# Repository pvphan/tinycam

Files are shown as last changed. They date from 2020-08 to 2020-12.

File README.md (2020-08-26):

tinycam
---

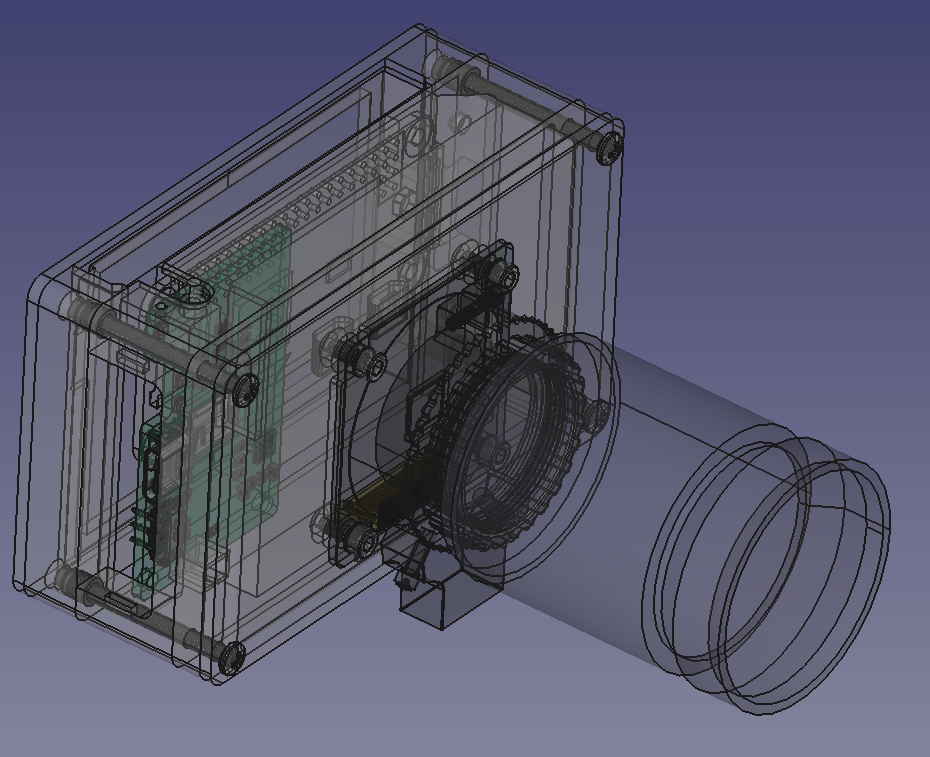
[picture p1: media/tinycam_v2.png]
tinycam_v2 CAD


This is a simple point-and-shoot camera, mostly an excuse to play with the new [Raspberry Pi High Quality camera](https://www.raspberrypi.org/products/raspberry-pi-high-quality-camera/) and ~~maybe~~ **also** a simple PCB for battery management.
The code is a very simple python script wrapping `raspistill`.
CAD is in [FreeCAD](https://www.freecadweb.org/), and any PCBs designed will be [KiCAD](https://kicad-pcb.org/).

Hardware requirements:

- [Raspberry Pi Zero W ($25)](https://www.amazon.com/CanaKit-Raspberry-Wireless-Official-Supply/dp/B071L2ZQZX/)
- [Samsung Evo+ 32 GB microSD card ($9)](https://www.amazon.com/gp/product/B00WR4IJBE)
- [iUniker 2.8" display ($23)](https://www.amazon.com/gp/product/B07H8ZY89H/)
- [Raspberry Pi High Quality camera ($50)](https://www.pishop.us/product/raspberry-pi-hq-camera/?src=raspberrypi)
- [Telephoto lens for HQ camera ($63)](https://www.pishop.us/product/16mm-telephoto-lens-for-raspberry-pi-hq-camera/)
- [Adafruit PowerBoost 1000 Charger ($20)](https://www.adafruit.com/product/2465)
- [tinycam PCB (~$35 to build)](pcb/)

#### next TODO:

- v2 of chassis to support button trigger and battery management
- auto upload to gphotos a la [eshmu/gphotos-upload](https://github.com/eshmu/gphotos-upload)
- support sleep / wake mode
- gallery mode (for local delete)

#### maybe later TODO:

- support video capture mode
- Qt overlay on top of preview for mode switching or adjusting 'manual' controls

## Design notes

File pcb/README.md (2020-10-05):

PCB
---

**WARNING: as of 2020-10-04, this design does not yet work! There is at least one significant deficiency in the PCB layout around the boost converter (TPS61090). I'm still working through the issues, but here are some links to seemingly related problems:**

- [Adafruit board with similar symptoms](https://forums.adafruit.com/viewtopic.php?f=19&t=110556&start=15)
- [TI forum - TPS61090: short circuits at SW pin 3,4 after working for some time](https://e2e.ti.com/support/power-management/f/196/t/642142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)

PCB designed in KiCAD, BOM in DigiKey importable format ([pcb.csv](pcb.csv)).
The PCB is [shared on OSHPark](https://oshpark.com/shared_projects/fBtFeIY9), cost is $11.90 for 3x board with normal prototyping service.

### 3D Model:

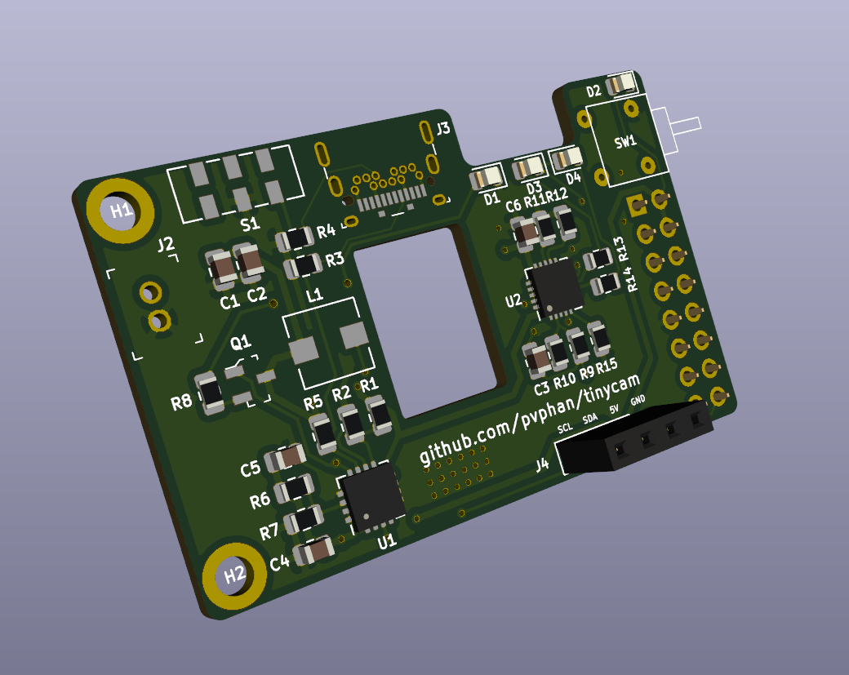
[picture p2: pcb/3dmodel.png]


### Schematic:

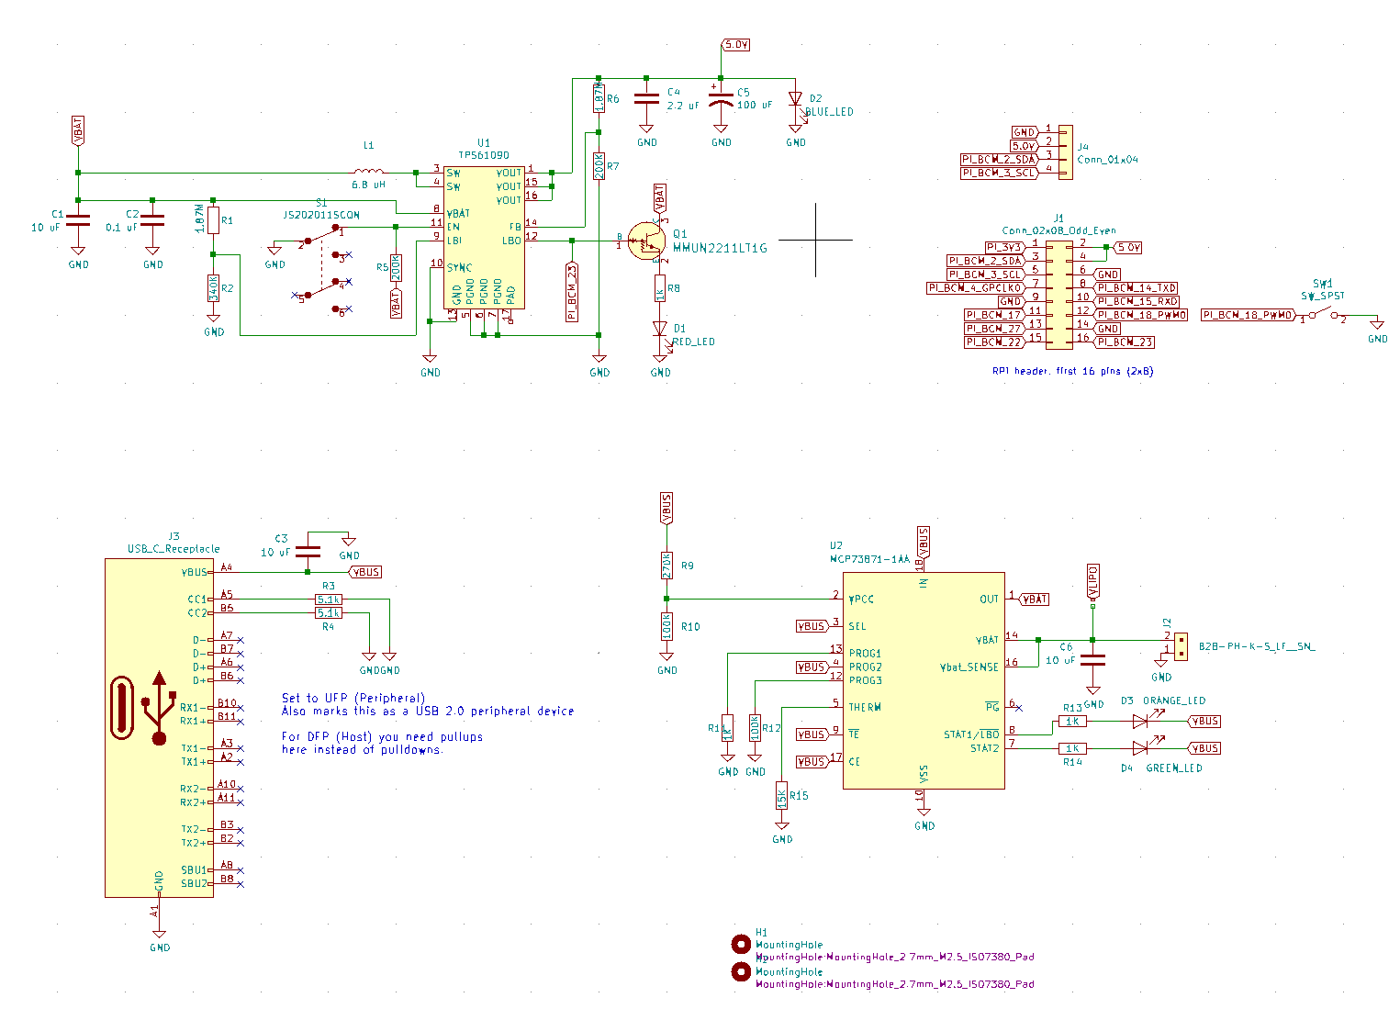
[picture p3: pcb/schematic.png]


### PCB Front:

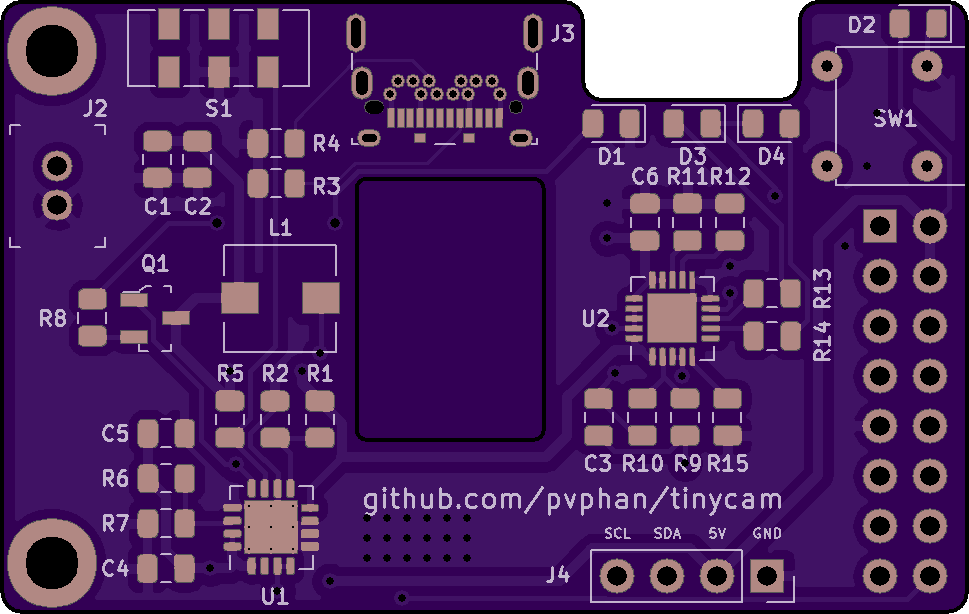
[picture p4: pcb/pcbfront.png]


### PCB Back:

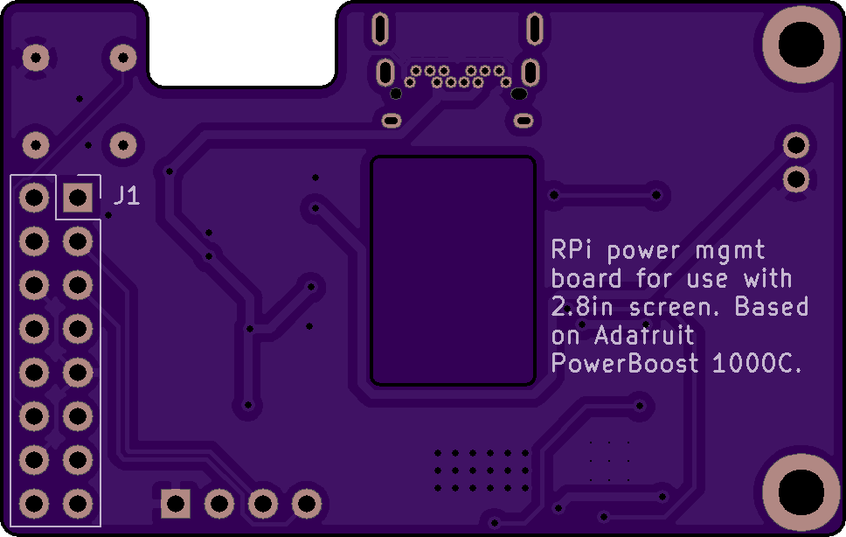
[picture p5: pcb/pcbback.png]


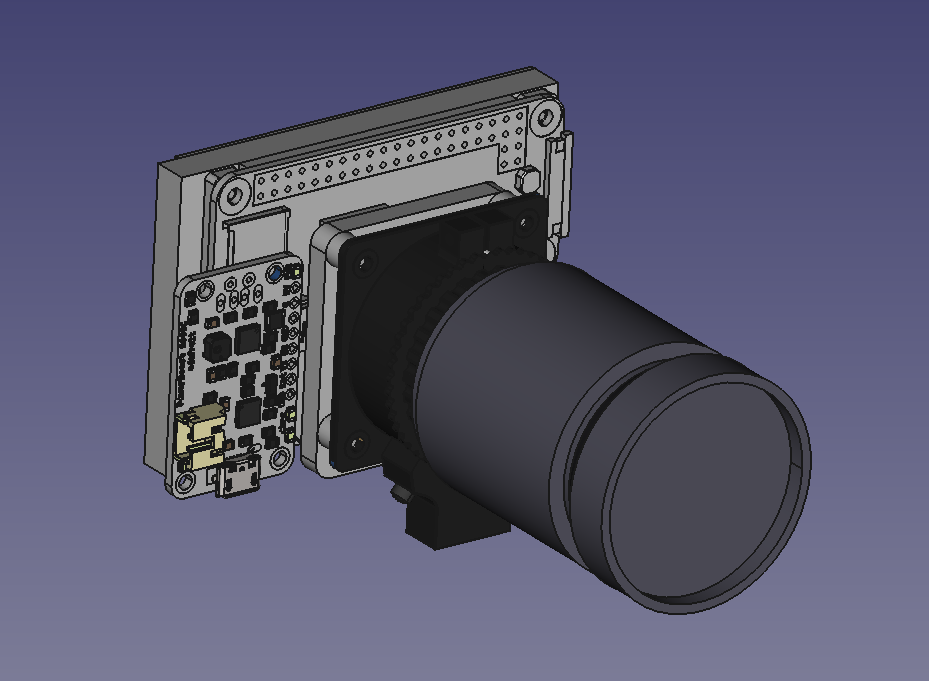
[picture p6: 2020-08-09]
media/tinycam_v1.png

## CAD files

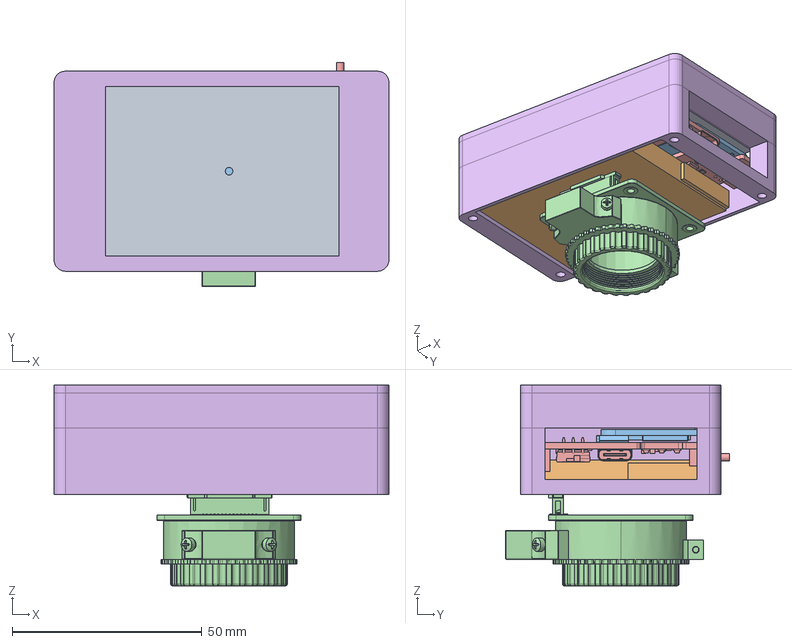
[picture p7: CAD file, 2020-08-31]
cad/main.FCStd
88.2 x 59.0 x 52.8 mm
iunikerscreen28_001
lipo2500mAh_001
rpizerow_001
hqcam_001
pcbpopulated_001
caseback_001

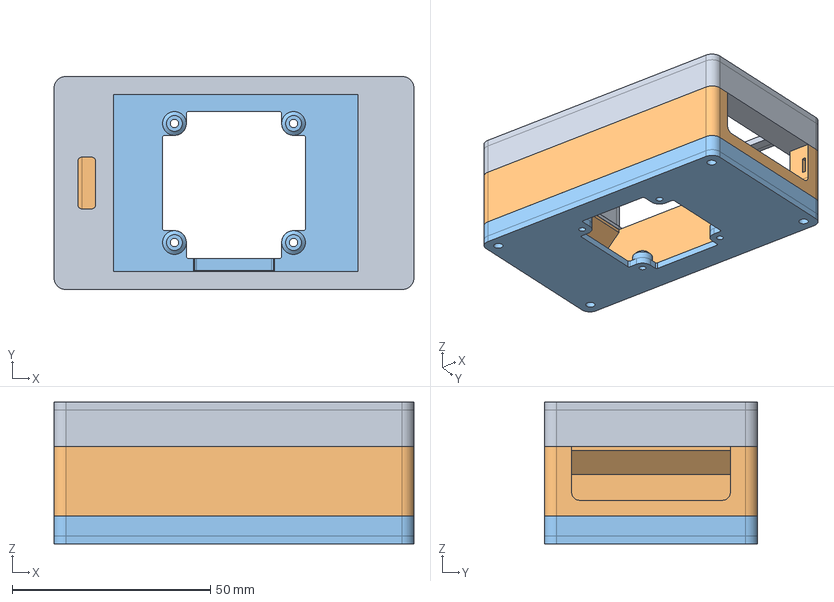
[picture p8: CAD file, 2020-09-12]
cad/caseback.FCStd
90.7 x 53.7 x 35.7 mm
Back
Middle
Front

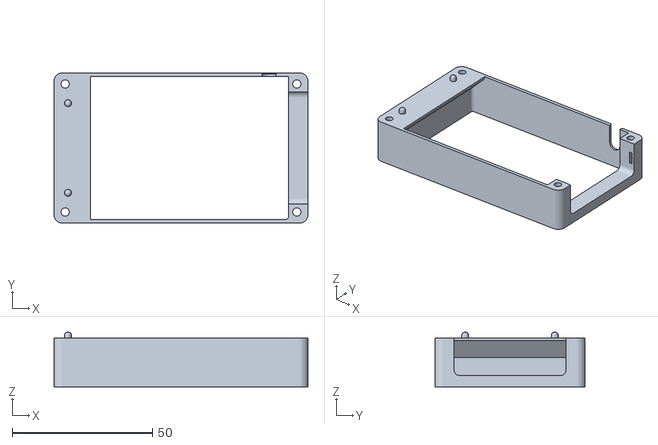
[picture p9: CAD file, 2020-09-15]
output/casemiddle.stl
90.7 x 53.7 x 19.5

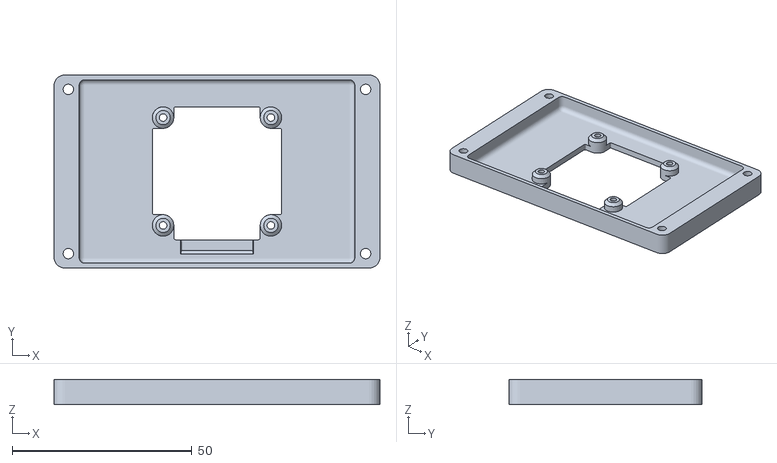
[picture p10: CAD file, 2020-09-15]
output/casefront.stl
90.7 x 53.7 x 7.00

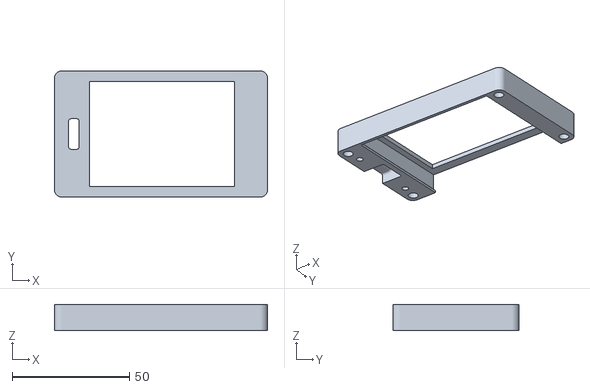
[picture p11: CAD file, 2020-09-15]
output/caseback.stl
90.7 x 53.7 x 11.3

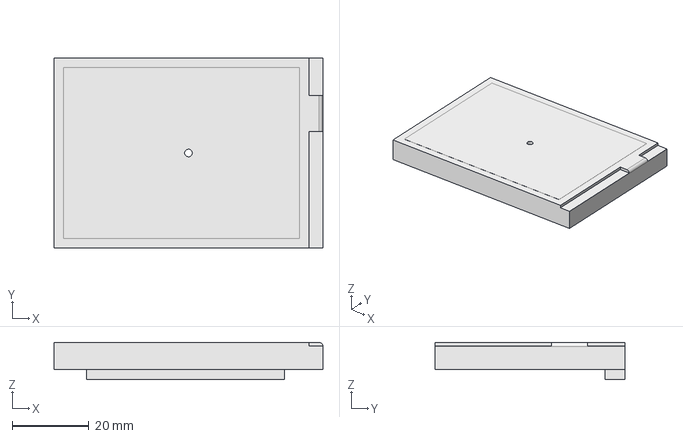
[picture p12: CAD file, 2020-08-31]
cad/iunikerscreen28.FCStd
70.2 x 49.7 x 9.75 mm

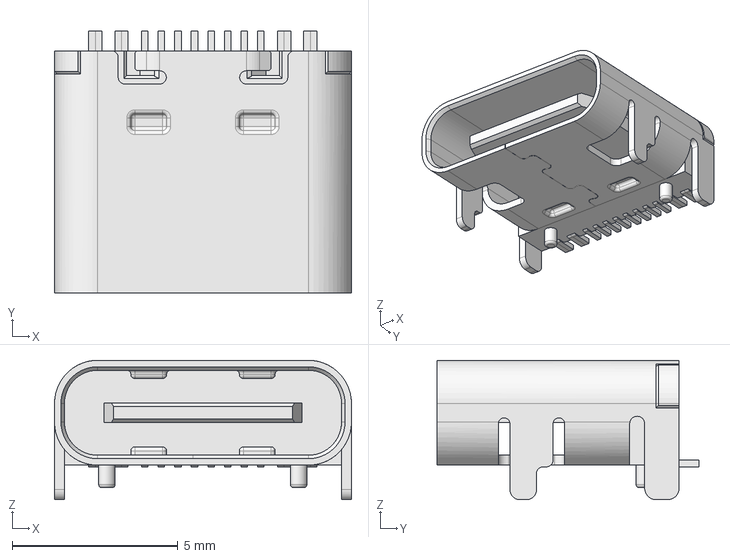
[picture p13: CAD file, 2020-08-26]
cad/usbcfemale.FCStd
8.95 x 7.90 x 4.20 mm

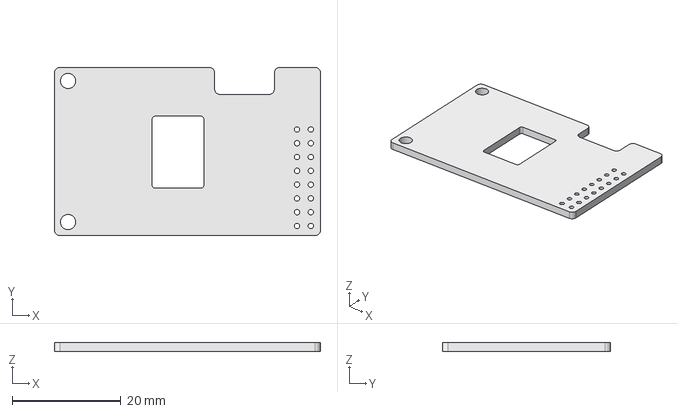
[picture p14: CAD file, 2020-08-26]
cad/pcb.FCStd
49.0 x 31.0 x 1.60 mm

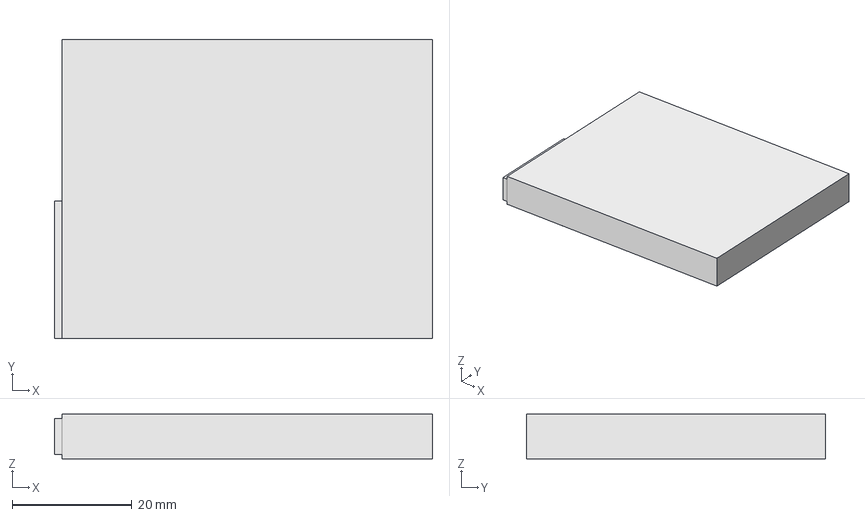
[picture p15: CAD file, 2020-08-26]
cad/lipo2500mAh.FCStd
63.2 x 50.0 x 7.50 mm

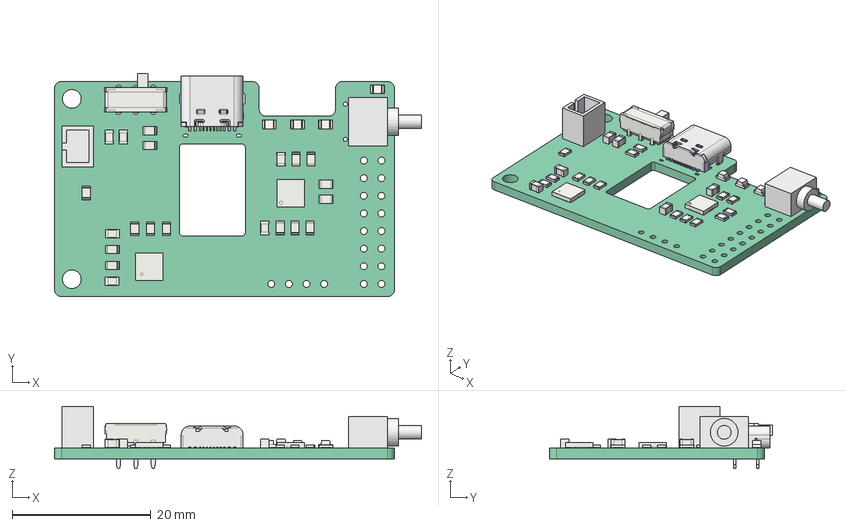
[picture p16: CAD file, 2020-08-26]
cad/pcbpopulated.FCStd
52.9 x 32.2 x 9.00 mm
Pcb_ca95
R15_R_0805_2012Metric_5F4384B2
R14_R_0805_2012Metric_5F41A5F7
R13_R_0805_2012Metric_5F41A621
R12_R_0805_2012Metric_5F41A5CD
R11_R_0805_2012Metric_5F41A5A3
R10_R_0805_2012Metric_5F438482
R9_R_0805_2012Metric_5F438452
R8_R_0805_2012Metric_5F418730
R7_R_0805_2012Metric_5F4188D7
R6_R_0805_2012Metric_5F418706
R5_R_0805_2012Metric_5F418601
R4_R_0805_2012Metric_5F41862B
R3_R_0805_2012Metric_5F4186A6
R2_R_0805_2012Metric_5F4185D7
R1_R_0805_2012Metric_5F4183FD
C5_C_0805_2012Metric_5F418A8F
C4_C_0805_2012Metric_5F418A5F
C2_C_0805_2012Metric_5F41895D
C1_C_0805_2012Metric_5F41892D
C3_C_0805_2012Metric_5F41A650
C6_C_0805_2012Metric_5F43930C
D1_LED_0805_2012Metric_5F4185A5
D2_LED_0805_2012Metric_5F4186D4
D3_LED_0805_2012Metric_5F41A51D
D4_LED_0805_2012Metric_5F41A4E7
S1_SW_CuK_JS202011AQN_DPDT_Angled_5F418324
U1_Texas_S_PVQFN_N16_EP27x27mm_5F41877F
U2_QFN-20-1EP_4x4mm_Pitch0.5mm_5F41A47B
usb-c
switch

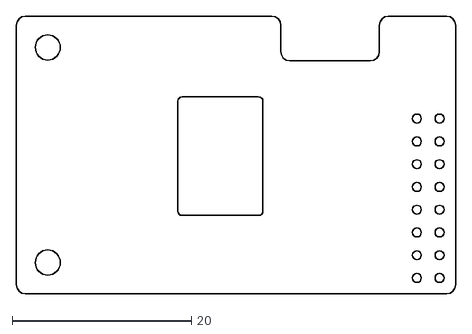
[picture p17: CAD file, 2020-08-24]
cad/pcbfrontface.dxf
49.0 x 31.0

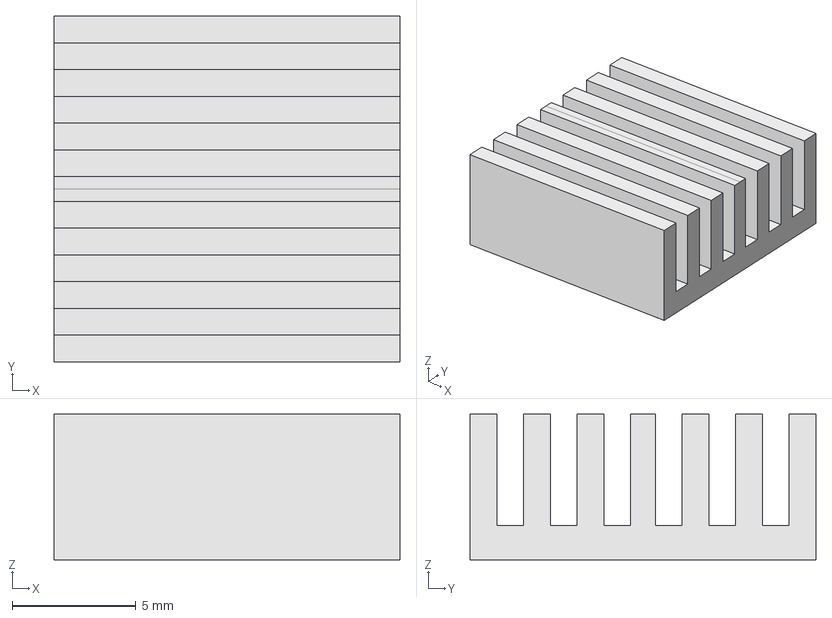
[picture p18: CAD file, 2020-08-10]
cad/heatsink.FCStd
14.0 x 14.0 x 5.90 mm

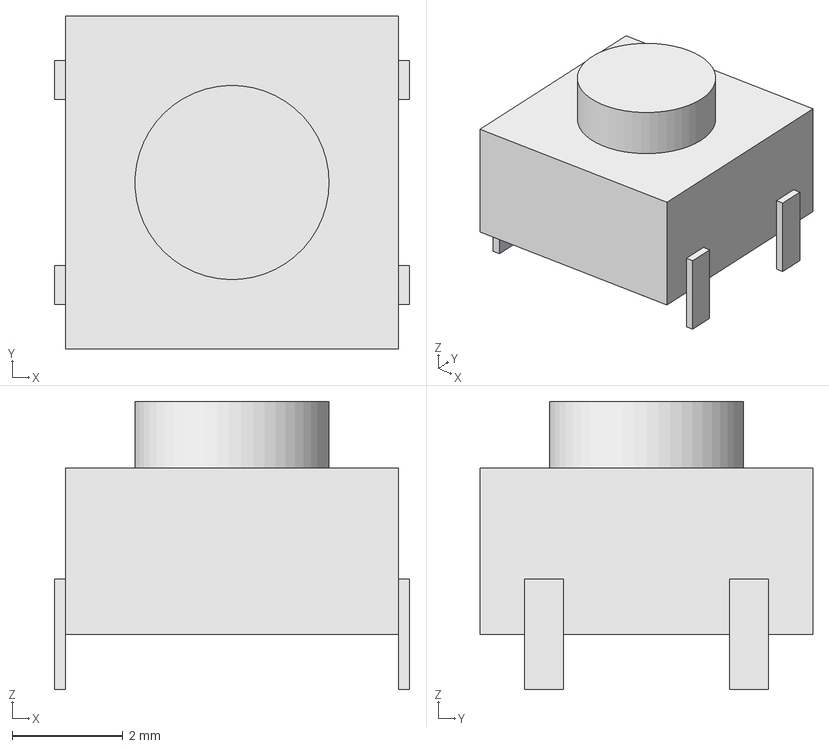
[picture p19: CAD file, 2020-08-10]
cad/button.FCStd
6.40 x 6.00 x 5.20 mm

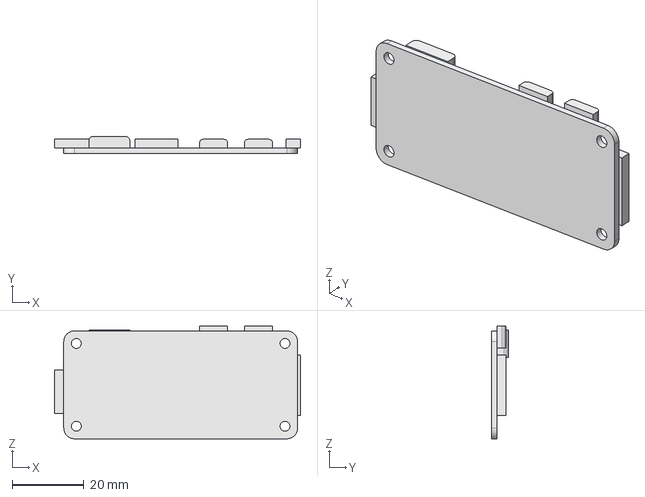
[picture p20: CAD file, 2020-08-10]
cad/pizerow2.FCStd
68.4 x 4.80 x 31.3 mm

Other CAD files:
cad/hqcam.FCStd
cad/PowerBoost1000C.FCStd
cad/telephotolens.FCStd
cad/picamadapter.fcstd
cad/92005A079.FCStd
cad/92290A056.FCStd
cad/94180A323.FCStd
cad/lensmountbracket.FCStd
cad/rpizerow.FCStd

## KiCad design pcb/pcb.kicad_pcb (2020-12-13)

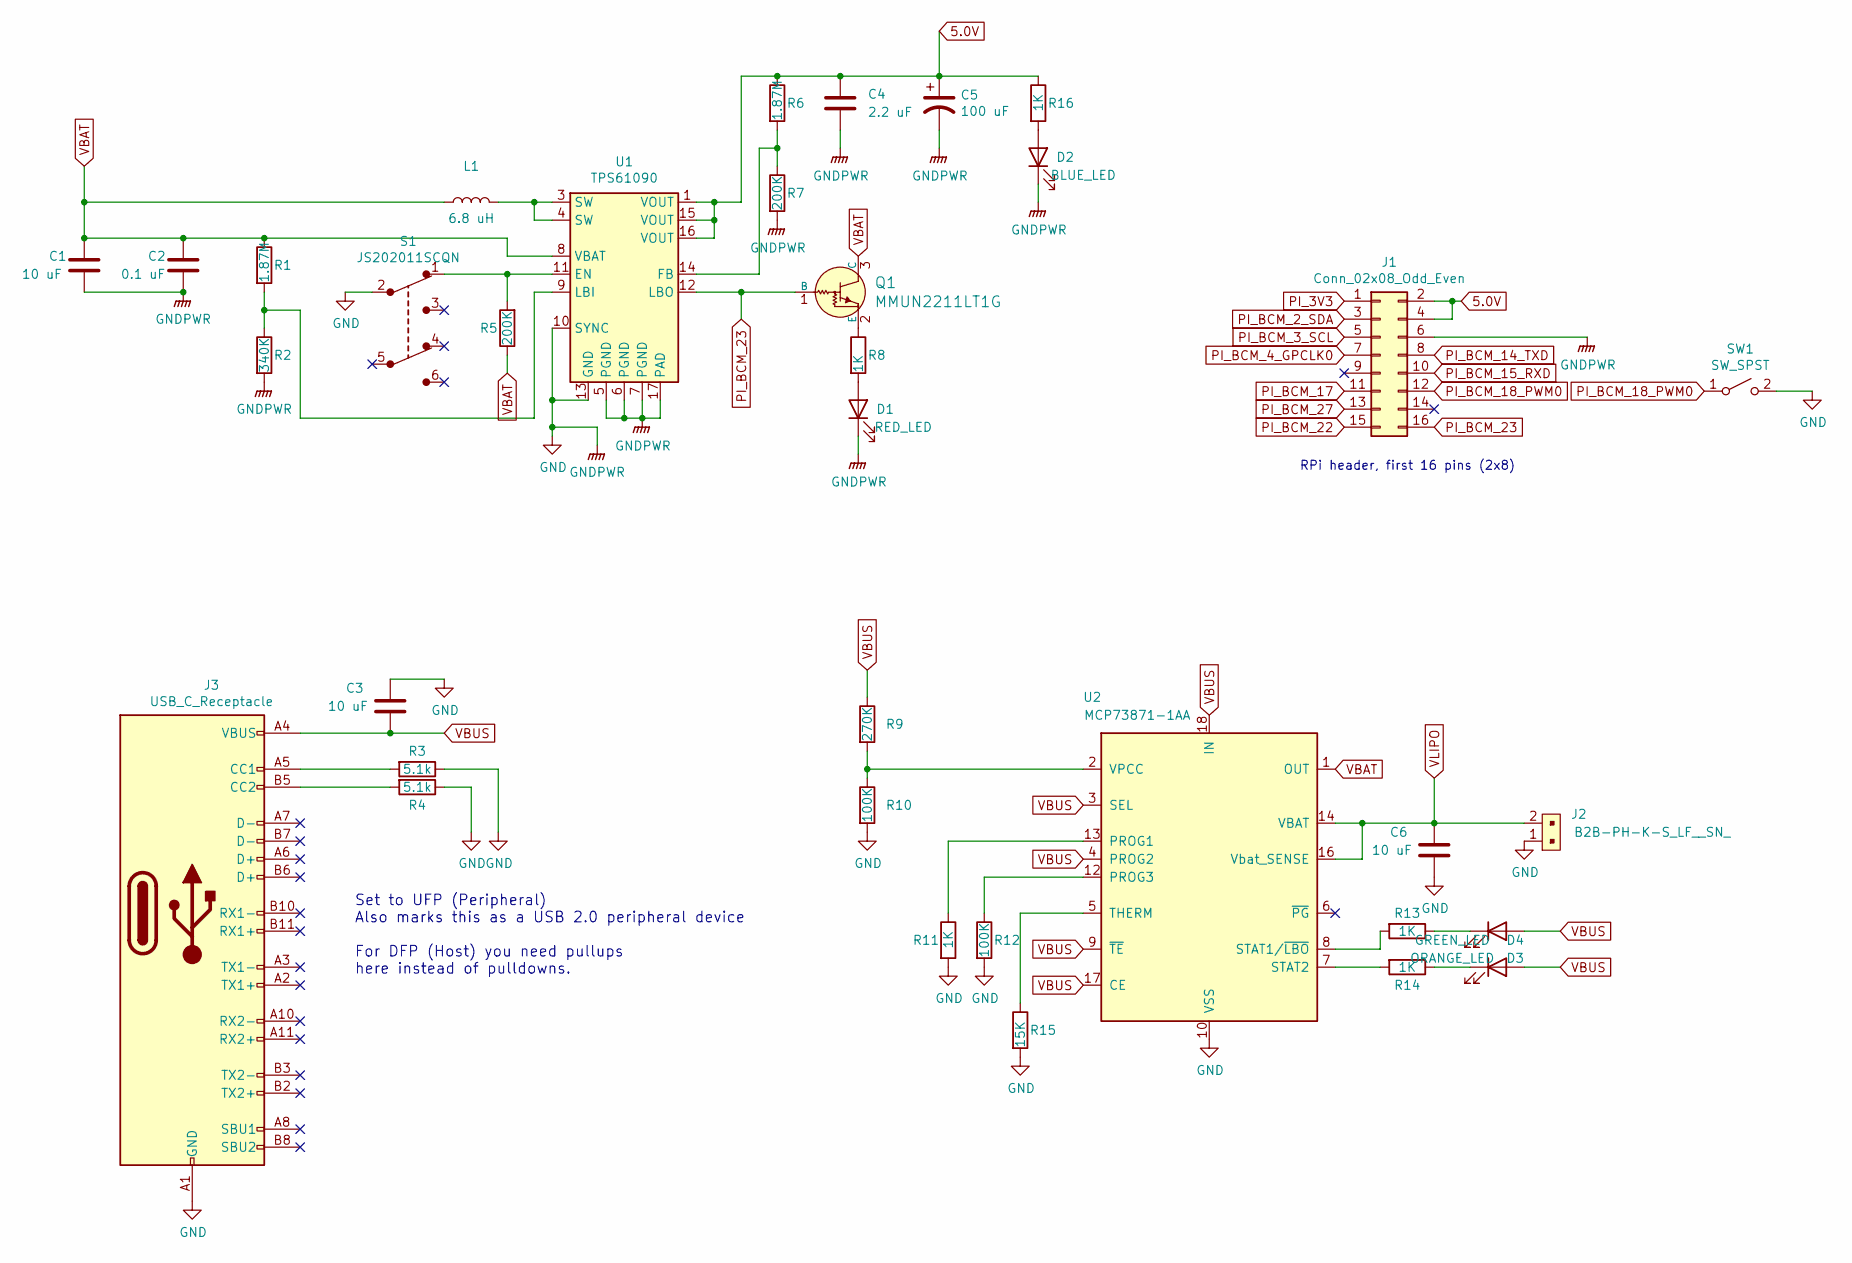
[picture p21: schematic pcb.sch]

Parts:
C1, C3, C6: 10 uF; C_0805_2012Metric
C2: 0.1 uF; C_0805_2012Metric
C4: 2.2 uF; C_0805_2012Metric
C5: 100 uF; CP_EIA-6032-20_AVX-F
D1: RED_LED; LED_0805_2012Metric
D2: BLUE_LED; LED_0805_2012Metric
D3: ORANGE_LED; LED_0805_2012Metric
D4: GREEN_LED; LED_0805_2012Metric
J1: Conn_02x08_Odd_Even; PinSocket_2x08_P2.54mm_Vertical
J2: B2B-PH-K-S_LF__SN_; PinHeader_1x2_P2mm_Drill1mm; MPN B2B-PH-K-S(LF)(SN); Digi-Key_PN 455-1704-ND
J3: USB_C_Receptacle; USB-C_Female_E8124-015-01
L1: 6.8 uH; L_Wuerth_WE-PD2-Typ-L
Q1: MMUN2211LT1G; SOT-23-3; MPN MMUN2133LT1G; Digi-Key_PN MMUN2133LT1GOSCT-ND
R1, R6: 1.87M; R_0805_2012Metric
R2: 340K; R_0805_2012Metric
R3, R4: 5.1k; R_0805_2012Metric
R5, R7: 200K; R_0805_2012Metric
R8, R11, R13, R14, R16: 1K; R_0805_2012Metric
R9: 270K; R_0805_2012Metric
R10, R12: 100K; R_0805_2012Metric
R15: 15K; R_0805_2012Metric
S1: JS202011SCQN; SW_DPDT_CK_JS202011JCQN; MPN JS202011SCQN; Digi-Key_PN 401-2002-1-ND
SW1: SW_SPST; FP11SPA1B1TP00
U1: TPS61090; Texas_S-PVQFN-N16_EP2.7x2.7mm_ThermalVias
U2: MCP73871-1AA; QFN-20-1EP_4x4mm_P0.5mm_EP2.5x2.5mm

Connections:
5.0V: C4.1, C5.1, J1.2, J1.4, R6.1, R16.1, U1.1 (VOUT), U1.15 (VOUT), U1.16 (VOUT)
GND: C1.2, C2.2, C3.1, C4.2, C5.2, C6.2, D1.1 (K), D2.1 (K), J1.6, J2.1, J3.A1 (GND), J3.A12 (GND), J3.B1 (GND), J3.B12 (GND), R2.2, R3.1, R4.1, R7.2, R10.2, R11.2, R12.2, R15.2, S1.2, SW1.2 (B), U1.5 (PGND), U1.6 (PGND), U1.7 (PGND), U1.10 (SYNC), U1.13 (GND), U1.17 (PAD), U2.10 (VSS), U2.11 (VSS), U2.21 (VSS)
unnamed: D1.2 (A), R8.2
unnamed: D2.2 (A), R16.2
unnamed: D3.1 (K), R13.1
unnamed: D4.1 (K), R14.1
unnamed: J3.A5 (CC1), R3.2
unnamed: J3.B5 (CC2), R4.2
unnamed: L1.2, U1.3 (SW), U1.4 (SW)
unnamed: Q1.2 (E), R8.1
unnamed: R1.2, R2.1, U1.9 (LBI)
unnamed: R5.2, S1.1, U1.11 (EN)
unnamed: R6.2, R7.1, U1.14 (FB)
unnamed: R9.2, R10.1, U2.2 (VPCC)
unnamed: R11.1, U2.13 (PROG1)
unnamed: R12.1, U2.12 (PROG3)
unnamed: R13.2, U2.8 (STAT1/~LBO~)
unnamed: R14.2, U2.7 (STAT2)
unnamed: R15.1, U2.5 (THERM)
PI_3V3: J1.1
PI_BCM_2_SDA: J1.3
PI_BCM_3_SCL: J1.5
PI_BCM_4_GPCLK0: J1.7
PI_BCM_14_TXD: J1.8
PI_BCM_15_RXD: J1.10
PI_BCM_17: J1.11
PI_BCM_18_PWM0: J1.12, SW1.1 (A)
PI_BCM_22: J1.15
PI_BCM_23: J1.16, Q1.1 (B), U1.12 (LBO)
PI_BCM_27: J1.13
VBAT: C1.1, C2.1, L1.1, Q1.3 (C), R1.1, R5.1, U1.8 (VBAT), U2.1 (OUT), U2.20 (OUT)
VBUS: C3.2, D3.2 (A), D4.2 (A), J3.A4 (VBUS), J3.A9 (VBUS), J3.B4 (VBUS), J3.B9 (VBUS), R9.1, U2.3 (SEL), U2.4 (PROG2), U2.9 (~TE), U2.17 (CE), U2.18 (IN), U2.19 (IN)
VLIPO: C6.1, J2.2, U2.14 (VBAT), U2.15 (VBAT), U2.16 (Vbat_SENSE)

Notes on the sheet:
RPi header, first 16 pins (2x8)
Set to UFP (Peripheral) Also marks this as a USB 2.0 peripheral device For DFP (Host) you need pullups here instead of pulldowns.

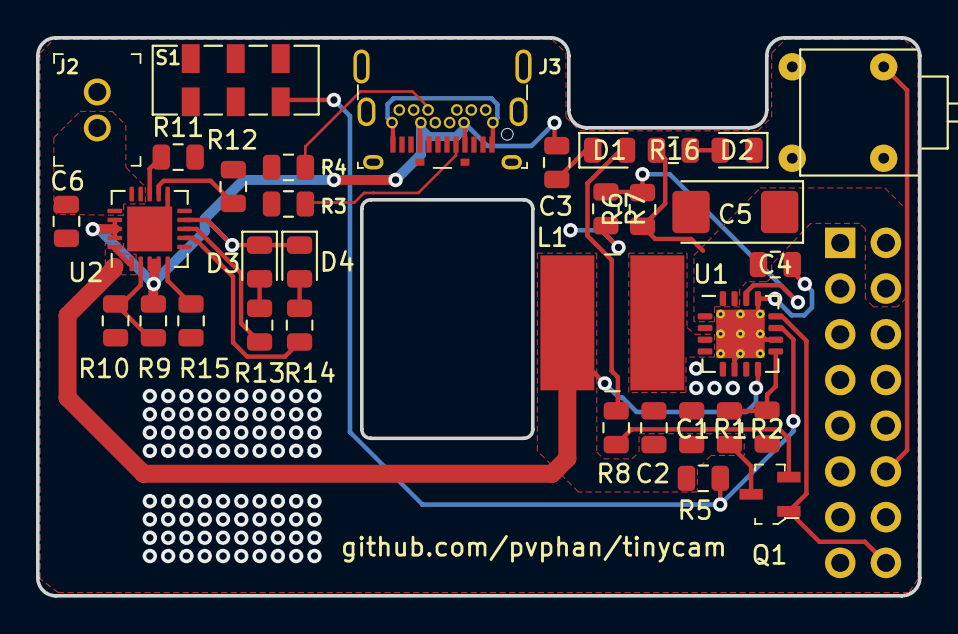
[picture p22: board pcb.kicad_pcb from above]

Board: 2 copper layers, 49.0 x 31.0 mm, 35 parts (1 on the bottom side), 24 nets.

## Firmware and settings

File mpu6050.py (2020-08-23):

"""
This program handles the communication over I2C
between a Raspberry Pi and a MPU-6050 Gyroscope / Accelerometer combo.
Made by: MrTijn/Tijndagamer, minor modifications by pvphan
Released under the MIT License
Copyright (c) 2015, 2016, 2017 MrTijn/Tijndagamer
"""
import time
from threading import Thread

class Mpu6050:
    # Global Variables
    GRAVITIY_MS2 = 9.80665
    address = None
    bus = None

    # Scale Modifiers
    ACCEL_SCALE_MODIFIER_2G = 16384.0
    ACCEL_SCALE_MODIFIER_4G = 8192.0
    ACCEL_SCALE_MODIFIER_8G = 4096.0
    ACCEL_SCALE_MODIFIER_16G = 2048.0

    GYRO_SCALE_MODIFIER_250DEG = 131.0
    GYRO_SCALE_MODIFIER_500DEG = 65.5
    GYRO_SCALE_MODIFIER_1000DEG = 32.8
    GYRO_SCALE_MODIFIER_2000DEG = 16.4

    # Pre-defined ranges
    ACCEL_RANGE_2G = 0x00
    ACCEL_RANGE_4G = 0x08
    ACCEL_RANGE_8G = 0x10
    ACCEL_RANGE_16G = 0x18

    GYRO_RANGE_250DEG = 0x00
    GYRO_RANGE_500DEG = 0x08
    GYRO_RANGE_1000DEG = 0x10
    GYRO_RANGE_2000DEG = 0x18

    # MPU-6050 Registers
    PWR_MGMT_1 = 0x6B
    PWR_MGMT_2 = 0x6C

    ACCEL_XOUT0 = 0x3B
    ACCEL_YOUT0 = 0x3D
    ACCEL_ZOUT0 = 0x3F

    TEMP_OUT0 = 0x41

    GYRO_XOUT0 = 0x43
    GYRO_YOUT0 = 0x45
    GYRO_ZOUT0 = 0x47

    ACCEL_CONFIG = 0x1C
    GYRO_CONFIG = 0x1B

    def __init__(self, address, hz, bus=1):
        import smbus
        self.address = address
        self.bus = smbus.SMBus(bus)
        # Wake up the MPU-6050 since it starts in sleep mode
        self.bus.write_byte_data(self.address, self.PWR_MGMT_1, 0x00)

        self.current_accel = None
        self.current_gyro = None
        self.hz = hz
        print("{} running @ {}hz.".format(type(self).__name__, hz))

    # I2C communication methods
    def read_i2c_word(self, register):
        """Read two i2c registers and combine them.

        register -- the first register to read from.
        Returns the combined read results.
        """
        # Read the data from the registers
        high = self.bus.read_byte_data(self.address, register)
        low = self.bus.read_byte_data(self.address, register + 1)

        value = (high << 8) + low

        if (value >= 0x8000):
            return -((65535 - value) + 1)
        else:
            return value

    # MPU-6050 Methods
    def get_temp(self):
        """Reads the temperature from the onboard temperature sensor of the MPU-6050.

        Returns the temperature in degrees Celcius.
        """
        raw_temp = self.read_i2c_word(self.TEMP_OUT0)

        # Get the actual temperature using the formule given in the
        # MPU-6050 Register Map and Descriptions revision 4.2, page 30
        actual_temp = (raw_temp / 340.0) + 36.53

        return actual_temp

    def set_accel_range(self, accel_range):
        """Sets the range of the accelerometer to range.

        accel_range -- the range to set the accelerometer to. Using a
        pre-defined range is advised.
        """
        # First change it to 0x00 to make sure we write the correct value later
        self.bus.write_byte_data(self.address, self.ACCEL_CONFIG, 0x00)

        # Write the new range to the ACCEL_CONFIG register
        self.bus.write_byte_data(self.address, self.ACCEL_CONFIG, accel_range)

    def read_accel_range(self, raw = False):
        """Reads the range the accelerometer is set to.

        If raw is True, it will return the raw value from the ACCEL_CONFIG
        register
        If raw is False, it will return an integer: -1, 2, 4, 8 or 16. When it
        returns -1 something went wrong.
        """
        raw_data = self.bus.read_byte_data(self.address, self.ACCEL_CONFIG)

        if raw is True:
            return raw_data
        elif raw is False:
            if raw_data == self.ACCEL_RANGE_2G:
                return 2
            elif raw_data == self.ACCEL_RANGE_4G:
                return 4
            elif raw_data == self.ACCEL_RANGE_8G:
                return 8
            elif raw_data == self.ACCEL_RANGE_16G:
                return 16
            else:
                return -1

    def get_accel_data(self, g = False):
        """Gets and returns the X, Y and Z values from the accelerometer.

        If g is True, it will return the data in g
        If g is False, it will return the data in m/s^2
        Returns a dictionary with the measurement results.
        """
        x = self.read_i2c_word(self.ACCEL_XOUT0)
        y = self.read_i2c_word(self.ACCEL_YOUT0)
        z = self.read_i2c_word(self.ACCEL_ZOUT0)

        accel_scale_modifier = None
        accel_range = self.read_accel_range(True)

        if accel_range == self.ACCEL_RANGE_2G:
            accel_scale_modifier = self.ACCEL_SCALE_MODIFIER_2G
        elif accel_range == self.ACCEL_RANGE_4G:
            accel_scale_modifier = self.ACCEL_SCALE_MODIFIER_4G
        elif accel_range == self.ACCEL_RANGE_8G:
            accel_scale_modifier = self.ACCEL_SCALE_MODIFIER_8G
        elif accel_range == self.ACCEL_RANGE_16G:
            accel_scale_modifier = self.ACCEL_SCALE_MODIFIER_16G
        else:
            print("Unkown range - accel_scale_modifier set to self.ACCEL_SCALE_MODIFIER_2G")
            accel_scale_modifier = self.ACCEL_SCALE_MODIFIER_2G

        x /= accel_scale_modifier
        y /= accel_scale_modifier
        z /= accel_scale_modifier

        if g is True:
            return {'x': x, 'y': y, 'z': z}
        elif g is False:
            x *= self.GRAVITIY_MS2
            y *= self.GRAVITIY_MS2
            z *= self.GRAVITIY_MS2
            return {'x': x, 'y': y, 'z': z}

    def set_gyro_range(self, gyro_range):
        """Sets the range of the gyroscope to range.

        gyro_range -- the range to set the gyroscope to. Using a pre-defined
        range is advised.
        """
        # First change it to 0x00 to make sure we write the correct value later
        self.bus.write_byte_data(self.address, self.GYRO_CONFIG, 0x00)

        # Write the new range to the ACCEL_CONFIG register
        self.bus.write_byte_data(self.address, self.GYRO_CONFIG, gyro_range)

    def read_gyro_range(self, raw = False):
        """Reads the range the gyroscope is set to.

        If raw is True, it will return the raw value from the GYRO_CONFIG
        register.
        If raw is False, it will return 250, 500, 1000, 2000 or -1. If the
        returned value is equal to -1 something went wrong.
        """
        raw_data = self.bus.read_byte_data(self.address, self.GYRO_CONFIG)

        if raw is True:
            return raw_data
        elif raw is False:
            if raw_data == self.GYRO_RANGE_250DEG:
                return 250
            elif raw_data == self.GYRO_RANGE_500DEG:
                return 500
            elif raw_data == self.GYRO_RANGE_1000DEG:
                return 1000
            elif raw_data == self.GYRO_RANGE_2000DEG:
                return 2000
            else:
                return -1

    def get_gyro_data(self):
        """Gets and returns the X, Y and Z values from the gyroscope.

        Returns the read values in a dictionary.
        """
        x = self.read_i2c_word(self.GYRO_XOUT0)
        y = self.read_i2c_word(self.GYRO_YOUT0)
        z = self.read_i2c_word(self.GYRO_ZOUT0)

        gyro_scale_modifier = None
        gyro_range = self.read_gyro_range(True)

        if gyro_range == self.GYRO_RANGE_250DEG:
            gyro_scale_modifier = self.GYRO_SCALE_MODIFIER_250DEG
        elif gyro_range == self.GYRO_RANGE_500DEG:
            gyro_scale_modifier = self.GYRO_SCALE_MODIFIER_500DEG
        elif gyro_range == self.GYRO_RANGE_1000DEG:
            gyro_scale_modifier = self.GYRO_SCALE_MODIFIER_1000DEG
        elif gyro_range == self.GYRO_RANGE_2000DEG:
            gyro_scale_modifier = self.GYRO_SCALE_MODIFIER_2000DEG
        else:
            print("Unkown range - gyro_scale_modifier set to self.GYRO_SCALE_MODIFIER_250DEG")
            gyro_scale_modifier = self.GYRO_SCALE_MODIFIER_250DEG

        x /= gyro_scale_modifier
        y /= gyro_scale_modifier
        z /= gyro_scale_modifier

        return {'x': x, 'y': y, 'z': z}

    def get_all_data(self):
        """Reads and returns all the available data."""
        temp = self.get_temp()
        accel = self.get_accel_data()
        gyro = self.get_gyro_data()

        return [accel, gyro, temp]

    def start_measure_loop(self, imu_cbs=[]):
        self._measure_thread = Thread(target=self.measure_loop, args=(imu_cbs,))
        self._measure_thread.daemon = True
        self._measure_thread.start()

    def measure_loop(self, imu_cbs):
        self.is_shutdown = False
        prev_measurement_time = None
        while not self.is_shutdown:
            measurement_time = time.time()
            if prev_measurement_time is not None:
                # weird fudge factor here to achieve closer to desired frequency
                if measurement_time - prev_measurement_time < 0.65 * (1 / self.hz):
                    continue
            self.current_accel = self.get_accel_data()
            self.current_gyro = self.get_gyro_data()
            imu_data = {
                "accel": self.current_accel,
                "gyro": self.current_gyro,
            }

            for imu_cb in imu_cbs:
                imu_cb(measurement_time, imu_data)
            prev_measurement_time = measurement_time

    def shutdown(self):
        print("{} shutting down".format(type(self).__name__))
        self.is_shutdown = True
        self._measure_thread.join(0.1)


if __name__ == "__main__":
    mpu = Mpu6050(0x68, 10)
    time.sleep(0.5)
    print("Temp: {:0.1f} C".format(mpu.get_temp()))
    accel_data = mpu.get_accel_data()
    print("a_x: {:0.3f} m/s^2".format(accel_data['x']))
    print("a_y: {:0.3f} m/s^2".format(accel_data['y']))
    print("a_z: {:0.3f} m/s^2".format(accel_data['z']))
    gyro_data = mpu.get_gyro_data()
    print("w_x: {:0.3f} deg/s".format(gyro_data['x']))
    print("w_y: {:0.3f} deg/s".format(gyro_data['y']))
    print("w_z: {:0.3f} deg/s".format(gyro_data['z']))

    mpu.start_measure_loop()

    while True:
        time.sleep(0.1)

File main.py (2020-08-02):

"""
Runs raspistill as subprocess, button press sends keyboard 'Enter' to trigger camera.
"""
import os
import signal
import subprocess
import time

import gpiozero


def main():
    raspistill_proc = subprocess.Popen(
            ["raspistill -t 0 -k -dt -fli 60hz -o /home/pi/Pictures/image%d.jpg"],
            stdin=subprocess.PIPE, shell=True)
    button = gpiozero.Button(21)

    def capture_image():
        print("got trigger")
        raspistill_proc.stdin.write("\n")

    button.when_pressed = capture_image

    print("program is running")
    try:
        while True:
            button.wait_for_press()
    finally:
        print("killing process")
        os.killpg(os.getpgid(raspistill_proc.pid), signal.SIGTERM)


if __name__ == "__main__":
    main()

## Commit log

2020-08-09 added CAD and image for v1
    [PowerBoost1000C.FCStd, hqcam.FCStd, lensmountbracket.FCStd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]
2020-08-10 started positioning models for v2 chassis
    [button.FCStd, heatsink.FCStd, iunikerscreen28.FCStd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]
2020-08-16 added initial pcb files
    [pcb.kicad_pcb, pcb.sch]
2020-08-17 excluding unused kicad files, added start of schematic with reference
    [file5FAC64C7.sch, pcb.sch]
2020-08-17 added some more components
    [pcb.sch]
2020-08-20 first pass of schematic complete
    [pcb.sch]
2020-08-22 updated schematic a bit, going to delete reference
    [pcb.sch]
2020-08-22 netlist has a bug it seems
    [pcb.kicad_pcb, pcb.sch]
2020-08-22 removed temp schematic
    [file5FAC64C7.sch]
2020-08-22 pcb is compiling again
    [pcb.kicad_pcb, pcb.sch]
2020-08-22 rough positioning of components
    [pcb.kicad_pcb]
2020-08-22 cleaned up layout a little
    [pcb.kicad_pcb]
2020-08-22 in work, PCB layup
    [iunikerscreen28.FCStd, lipo2500mAh.FCStd, main.FCStd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]
2020-08-22 added PCB models
    [main.FCStd, pcb.FCStd, pcb.kicad_pcb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]
2020-08-23 added IMU script
2020-08-23 updated cut profile fillets, 4 corners now the same
    [main.FCStd, pcb.FCStd]
2020-08-24 updated cuts and placements, all 0805 SMD
    [pcb.kicad_pcb, pcb.sch, pcbfrontface.dxf]
2020-08-24 updated pcb a little
    [pcb.kicad_pcb]
2020-08-24 layed most of the traces
    [pcb.kicad_pcb]
2020-08-24 finished v1 of pcb
    [pcb.kicad_pcb]
2020-08-24 added digikey BOM, finalized v1 layout
    [pcb.csv, pcb.kicad_pcb]
2020-08-24 added PCB media files
    [pcb.csv, pcb.sch]
2020-08-24 shared board on OSHPark, linked
2020-08-26 updated populated PCB
    [lipo2500mAh.FCStd, main.FCStd, pcb.FCStd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]
2020-08-27 fixed some mistakes
    [pcb.csv, pcb.kicad_pcb, pcb.sch]
2020-08-31 designing case, still in work
    [caseback.FCStd, iunikerscreen28.FCStd, main.FCStd]
2020-09-05 revd to v1.1
    [pcb.kicad_pcb, pcb.sch]
2020-09-05 cleaned up a few traces
    [pcb.kicad_pcb]
2020-09-05 increased track widths for power
    [pcb.kicad_pcb]
2020-09-05 updated PCB, oshpark link, and media
    [pcb.kicad_pcb]
2020-09-12 camera case design complete, not yet test printed
    [92005A079.FCStd, 92290A056.FCStd, 94180A323.FCStd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]
2020-09-15 moved output, added stencil (90%)
    [caseback.stl, casefront.stl, casemiddle.stl]
2020-09-15 moved pcb BOM to outputs
    [pcb.csv]
2020-10-05 added warning, still need to fix board
    [pcb.sch]
2020-11-22 updated PCB following boost converter design guidelines
    [pcb.kicad_pcb, pcb.sch]
2020-11-22 a little cleanup
    [pcb.kicad_pcb]
2020-12-13 updated schematic
    [pcb.kicad_pcb, pcb.sch]
